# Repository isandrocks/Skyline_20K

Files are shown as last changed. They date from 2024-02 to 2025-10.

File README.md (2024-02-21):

# Skyline_20K
 This is a 20 key keypad with really REALLY bright lights!

 This board has 12 4960 Neopixel LED's. they are all facing down for a massive aount of under glow if I make a white 3D printed case for it, or I can just use it as a searchlight. 

The keypad PCB has 2 brakepoints so it can be snapped off and then connected with a right angle header.

this also acts as a sort of stand for the keypad if you dont make a case for it.

skyline_3d 

skyline_PCB

Test configuration for the snap away parts 

skyline_mu

### First prototype done but i messed up the pads for the lighting so i need to redo some parts 

skyline_proto
skyline_proto

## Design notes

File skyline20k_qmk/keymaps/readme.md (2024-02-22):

# skyline20k

skyline20k

*A short description of the keyboard/project*

* Keyboard Maintainer: [iSandRocks](https://github.com/iSandRocks)
* Hardware Supported: *The PCBs, controllers supported*
* Hardware Availability: *Links to where you can find this hardware*

Make example for this keyboard (after setting up your build environment):

    make skyline20k:default

Flashing example for this keyboard:

    make skyline20k:default:flash

See the [build environment setup](https://docs.qmk.fm/#/getting_started_build_tools) and the [make instructions](https://docs.qmk.fm/#/getting_started_make_guide) for more information. Brand new to QMK? Start with our [Complete Newbs Guide](https://docs.qmk.fm/#/newbs).

## Bootloader

Enter the bootloader in 3 ways:

* **Bootmagic reset**: Hold down the key at (0,0) in the matrix (usually the top left key or Escape) and plug in the keyboard
* **Physical reset button**: Briefly press the button on the back of the PCB - some may have pads you must short instead
* **Keycode in layout**: Press the key mapped to `QK_BOOT` if it is available

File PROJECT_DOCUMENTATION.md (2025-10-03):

# Skyline_20K Project Documentation

## Project Overview

### Purpose and Goals
Skyline_20K is a custom 20-key mechanical keypad/macropad featuring extremely bright RGB underglow lighting. This project combines hardware design, PCB engineering, 3D modeling, and firmware development to create a highly functional and visually striking input device for enthusiasts and power users.

### Problem It Solves
The project addresses several needs in the mechanical keyboard community:
- **Customizable Macro Input**: Provides 20 programmable keys for shortcuts, macros, and special functions
- **Visual Impact**: Features 12 high-intensity 4960 Neopixel LEDs for dramatic underglow effects
- **Modular Design**: Includes breakaway sections that can be snapped off and reconnected, offering flexible form factors
- **Open Source Hardware**: Fully open-source design allows community modifications and learning

### Why It Matters
This project demonstrates the intersection of hardware engineering, firmware development, and maker culture. It showcases:
- Complete end-to-end product development from PCB design to working firmware
- Integration of multiple technologies (USB, RGB lighting, QMK firmware)
- Practical application of microcontroller programming
- Community-driven hardware development practices

## Features & Functionality

### Key Features

#### Hardware Features
1. **20-Key Matrix Layout**: 5×4 grid layout optimized for numpad-style usage and macro programming
2. **Ultra-Bright RGB Lighting**: 
   - 12× 4960 Neopixel LEDs
   - All LEDs face downward for maximum underglow effect
   - Can serve as a functional searchlight due to light intensity
   - Optimized for white 3D-printed cases to maximize light diffusion
3. **Modular PCB Design**:
   - Two breakpoints allow sections to snap off
   - Right-angle header connections for reassembly
   - Detached sections can act as a stand for the keypad
4. **ATmega328P Microcontroller**: Reliable, well-documented 8-bit AVR processor
5. **USB Connectivity**: Direct USB interface using custom bootloader

#### Firmware Features
1. **QMK Firmware Support**: Industry-standard mechanical keyboard firmware
2. **Vial Configuration**: Real-time keymap editing without reflashing
3. **Multiple Layers**: Support for function layers and complex key mappings
4. **RGB Effects**: Pre-configured rainbow mood lighting effect with customizable parameters
5. **N-Key Rollover (NKRO)**: Full anti-ghosting support
6. **Bootmagic**: Configuration features accessible via key combinations

### Technical Highlights

#### Frameworks & Libraries
- **QMK Firmware**: Open-source keyboard firmware framework
- **WS2812 Driver**: Bitbang implementation for LED control with precise timing
- **USBaspLoader**: Custom USB bootloader for AVR microcontrollers
- **Vial**: Real-time keyboard configuration tool

#### Tools & Technologies
- **KiCad**: PCB design and schematic capture
  - Full PCB layout files (`.kicad_pcb`)
  - Schematic files (`.kicad_sch`)
  - Gerber files for manufacturing
- **3D Printing**: STL files for enclosure design (v4 and v7 variants)
- **AVRDUDE**: AVR programming tool for flashing firmware and bootloader
- **USB Protocol**: Custom USB device implementation

### Unique Aspects

1. **Breakaway Design**: Unlike typical keyboards, this features intentional breakpoints for modularity
2. **Extreme Lighting**: The 4960 Neopixel LEDs are significantly brighter than standard WS2812B LEDs
3. **Downward-Facing LEDs**: Unconventional LED orientation creates unique underglow effects
4. **Dual-Purpose Stand**: Broken-off sections serve as a functional stand
5. **Custom USB Bootloader**: Uses USBaspLoader instead of standard Arduino bootloader
6. **Complete Open Source**: Full hardware and firmware files available

## Architecture & Design

### High-Level Structure

The project consists of four main components:

```
Skyline_20K/
├── Hardware Design (KiCad files)
├── Firmware (QMK-based)
├── 3D Models (STL files)
└── Bootloader (USBaspLoader)
```

### Core Components

#### 1. Hardware Layer (PCB Design)
**Files**: `20Key_macropad.kicad_*`, Gerber files
- **Matrix Wiring**: 5 rows × 4 columns = 20 keys
  - Rows: B0, B1, B2, D6, D7
  - Columns: C0, C1, C2, C3
- **Diode Direction**: COL2ROW configuration prevents ghosting
- **LED Controller**: Pin C4 drives the WS2812 LED chain
- **USB Interface**: Native USB pins on ATmega328P
- **Power Management**: USB bus-powered design

**Mechanical Features**:
- Cherry MX compatible switch footprints
- Breakpoints with reinforced traces
- Right-angle header mounting holes
- Mounting holes for case attachment

#### 2. Firmware Layer (QMK)
**Location**: `skyline20k_qmk/`

**Key Files**:
- `config.h`: Hardware configuration and feature settings
- `rules.mk`: Build system configuration and feature flags
- `info.json`: Keyboard metadata and layout definition
- `keymaps/`: Multiple keymap configurations
  - `default/`: Basic functional layout
  - `vial/`: Real-time configurable layout with Vial support

**Configuration Highlights**:
```c
// LED Configuration
#define WS2812_DI_PIN C4      // LED data pin
#define RGBLED_NUM 12          // 12 LEDs total
#define RGBLIGHT_LIMIT_VAL 255 // Maximum brightness

// WS2812 Timing (bitbang driver)
WS2812_TIMING = 1200
WS2812_T1H = 640    // High pulse for '1'
WS2812_T0H = 320    // High pulse for '0'
WS2812_TRST_US = 75 // Reset time
```

#### 3. Bootloader Layer (USBaspLoader)
**Location**: `USBaspLoader/`

- **Purpose**: Allows firmware updates via USB without external programmer
- **Protocol**: Emulates USBasp programmer for compatibility with AVRDUDE
- **Features**:
  - Self-protection from accidental overwrites
  - Update capability for bootloader itself
  - Configurable entry conditions (button/jumper)

**Fuse Settings for ATmega328P**:
```
Low Fuse:  0xFF (16MHz external crystal)
High Fuse: 0xD8 (Bootloader enabled)
Ext Fuse:  0xFF (BOD disabled)
```

#### 4. 3D Model Layer
**Files**: `20Key_macropad v4.stl`, `20Key_macropad v7.stl`
- Designed for white filament to maximize light diffusion
- Multiple versions for iteration and improvements
- Mounting features for PCB attachment
- Provision for breakaway section stand

### Data Flow

1. **Key Press**: Physical switch closes → Matrix scan detects
2. **Processing**: QMK firmware processes → Keymap lookup → USB HID report
3. **USB Communication**: Report sent to host computer
4. **LED Control**: Parallel process drives WS2812 LEDs via bitbang protocol
5. **Configuration**: Vial allows real-time updates via USB without reflashing

### Design Patterns

1. **Matrix Scanning**: Efficient key detection with minimal I/O pins
2. **Interrupt-Driven USB**: Responsive USB communication
3. **State Machine**: LED effects implemented as state machines
4. **Layer System**: Multiple keymap layers for extended functionality
5. **Modular Configuration**: Separated hardware config from behavior logic

## Installation & Setup

### Prerequisites

#### Hardware Requirements
- Skyline_20K PCB (manufactured from Gerber files)
- 20× Cherry MX compatible switches
- 20× Keycaps
- 12× 4960 Neopixel RGB LEDs
- ATmega328P microcontroller (pre-soldered or socketed)
- USB cable (appropriate connector for your design)
- Optional: 3D printed case (STL files provided)

#### Software Requirements
- **QMK Build Environment**: 
  - QMK CLI tools
  - AVR-GCC toolchain
  - ARM GCC (for certain features)
- **AVRDUDE**: For flashing bootloader and firmware
- **Python 3.7+**: Required by QMK CLI
- **Git**: For cloning repositories
- **Optional**: Vial configurator for keymap customization

### Initial Hardware Setup

#### 1. Bootloader Installation
If starting with a blank ATmega328P, you'll need an ISP programmer:

```bash
# Set fuses (enables bootloader, sets clock to external 16MHz)
avrdude -c avrisp -p m328p -P /dev/ttyUSB0 -v -u -U lfuse:w:0xFF:m
avrdude -c avrisp -p m328p -P /dev/ttyUSB0 -v -u -U hfuse:w:0xD8:m
avrdude -c avrisp -p m328p -P /dev/ttyUSB0 -v -u -U efuse:w:0xFF:m

# Flash USBaspLoader
cd USBaspLoader
make DEVICE=atmega328p
make flash
```

**Note**: Replace `/dev/ttyUSB0` with your programmer's port (COM port on Windows).

#### 2. Assembly Steps
1. Solder LEDs to PCB (observe polarity!)
2. Solder switches into PCB
3. Install microcontroller (if socketed) or verify pre-soldered installation
4. Connect USB cable
5. Optional: Snap apart breakaway sections if desired
6. Optional: Install in 3D printed case

### Firmware Setup

#### Building QMK Firmware

1. **Install QMK Environment**:
```bash
# Install QMK CLI
python3 -m pip install --user qmk

# Setup QMK
qmk setup
```

2. **Clone Skyline_20K Repository**:
```bash
git clone https://github.com/isandrocks/Skyline_20K.git
cd Skyline_20K
```

3. **Link Keyboard to QMK**:
```bash
# Create symlink in QMK keyboards directory
ln -s $(pwd)/skyline20k_qmk ~/qmk_firmware/keyboards/skyline20k
```

4. **Build Firmware**:
```bash
# Build default keymap
qmk compile -kb skyline20k -km default

# Or build Vial keymap for real-time configuration
qmk compile -kb skyline20k -km vial
```

#### Flashing Firmware

**Using USBaspLoader** (after initial bootloader installation):
```bash
# Enter bootloader mode (press reset button or configured key combo)
qmk flash -kb skyline20k -km default

# AVRDUDE will automatically detect and flash
```

**Manual AVRDUDE command**:
```bash
avrdude -c usbasp -p m328p -U flash:w:skyline20k_default.hex
```

### Testing

1. **LED Test**: Upon power-up, LEDs should illuminate with default rainbow mood effect
2. **Key Test**: Use a key tester website or text editor to verify all 20 keys respond
3. **Layer Test**: Test function layer keys (if configured)
4. **USB Test**: Verify stable USB connection (no disconnects)

### Vial Configuration (Optional)

1. **Install Vial**:
   - Download from https://get.vial.today/
   - Flash `vial` keymap variant

2. **Configure**:
   - Launch Vial application
   - Connect Skyline_20K
   - Customize keymaps in real-time
   - Adjust RGB settings
   - Save configuration (stored in EEPROM)

## Usage

### Basic Operation

#### Default Keymap (Layer 0)
The default layout is configured as a standard numpad-style layout:
```
ESC   1     2     3
4     5     6     7
8     9     0     BSPC
TAB   Q     W     E
R     T     Y     U
```
(See `skyline20k_qmk/keymaps/default/keymap.c` for complete mapping)

#### Function Layer (Layer 1)
Access by holding the MO(1) key:
- Function keys (F1-F12)
- Arrow keys for navigation
- Volume controls
- Additional media keys

### Example Workflows

#### 1. **Number Pad Entry**
- Use as a dedicated number pad for data entry
- Efficient for spreadsheet work or calculator operations

#### 2. **Macro Programming**
```c
// Example custom macro in keymap.c
case MACRO_1:
    if (record->event.pressed) {
        SEND_STRING("git commit -m \"\"" SS_TAP(X_LEFT));
    }
    return false;
```

#### 3. **Media Control Center**
- Program keys for play/pause, next/previous track
- Volume controls
- Application launching

#### 4. **Gaming Hotkeys**
- Program frequently used game commands
- Quick access to inventory, skills, or macros
- Stream control for content creators

#### 5. **Creative Software Shortcuts**
- Photoshop/GIMP tool selection
- Video editing timeline controls
- 3D modeling shortcuts

### RGB Lighting Control

#### Default Effects
- **Rainbow Mood**: Slowly cycling rainbow effect (enabled by default)
- Brightness: Maximum (255)
- Hue start: 8
- Saturation: Maximum

#### Customizing RGB (via QMK)
Edit `skyline20k_qmk/config.h`:
```c
#define RGBLIGHT_HUE_STEP 8      // Hue change increment
#define RGBLIGHT_SAT_STEP 17     // Saturation change increment
#define RGBLIGHT_VAL_STEP 17     // Brightness change increment
#define RGBLIGHT_LIMIT_VAL 255   // Maximum brightness (reduce if too bright)
```

#### Available RGB Keycodes (add to keymap)
- `RGB_TOG`: Toggle RGB on/off
- `RGB_MOD`: Cycle through effects
- `RGB_HUI/RGB_HUD`: Increase/decrease hue
- `RGB_SAI/RGB_SAD`: Increase/decrease saturation
- `RGB_VAI/RGB_VAD`: Increase/decrease brightness

### Advanced Usage

#### Custom Firmware Modifications
1. Edit keymap in `skyline20k_qmk/keymaps/default/keymap.c`
2. Add custom RGB effects in keymap
3. Implement tap dance or leader key sequences
4. Add custom OLED display support (requires hardware mod)

#### Bootloader Entry
- **Hardware Method**: Short the bootloader entry pins during power-up
- **Software Method**: Configure a key combo to enter bootloader mode
- **Emergency**: Use ISP programmer to force reflash if bootloader corrupted

## Development Notes

### Current Status
- **Hardware**: Prototype completed with minor issues identified
- **PCB Issue**: First prototype had incorrect LED pad layout (documented in README)
- **Firmware**: Functional with QMK and Vial support
- **Case Design**: Multiple STL iterations available (v4, v7)

### Known Issues and Limitations

1. **LED Pad Misalignment** (Prototype v1):
   - Issue: LED pads not properly aligned for 4960 Neopixels
   - Status: Identified, requires PCB revision
   - Workaround: Manual wire connections for prototype testing

2. **Brightness Warning**:
   - 12× 4960 Neopixels at full brightness draw significant current
   - May exceed USB 2.0 500mA limit
   - Recommendation: Limit brightness or use powered USB hub

3. **Bootloader Entry**:
   - Requires physical button or jumper (hardware-dependent)
   - Software bootloader entry would improve user experience

4. **Documentation**:
   - Some documentation files incomplete (placeholders in QMK readme)
   - Assembly instructions could be more detailed

### Planned Improvements

#### Short Term
- [ ] Revise PCB to fix LED pad alignment
- [ ] Complete assembly documentation
- [ ] Add build photos to repository
- [ ] Create step-by-step soldering guide

#### Medium Term
- [ ] Design improved case with better LED diffusion
- [ ] Add rotary encoder support (hardware revision)
- [ ] Implement RGB per-key lighting mode
- [ ] Create configuration web interface
- [ ] Add OLED display support

#### Long Term
- [ ] Wireless variant (Bluetooth/2.4GHz)
- [ ] Hot-swap socket support for switches
- [ ] Split keyboard variant using breakaway design
- [ ] Metal case option for premium version
- [ ] Group buy or small production run

### Development Environment

#### Building from Source
```bash
# Clone repository
git clone https://github.com/isandrocks/Skyline_20K.git
cd Skyline_20K

# Build QMK firmware
cd skyline20k_qmk
qmk compile -kb skyline20k -km default

# Build bootloader (if modifying)
cd ../USBaspLoader
make clean
make DEVICE=atmega328p
```

#### Contributing
This is an open-source project welcoming contributions:
- PCB improvements
- Firmware enhancements
- Case design variations
- Documentation updates
- Bug fixes

### Testing Checklist
- [ ] All 20 keys register correctly
- [ ] No key ghosting in any combination
- [ ] All 12 LEDs illuminate
- [ ] RGB effects run smoothly
- [ ] USB connection stable
- [ ] No excessive heat generation
- [ ] Case fit (if using 3D printed enclosure)
- [ ] Breakaway mechanism works cleanly

## Potential Impact

### Who Benefits

1. **Mechanical Keyboard Enthusiasts**:
   - Custom hardware design inspiration
   - Learning resource for PCB design
   - Platform for experimentation

2. **Content Creators & Streamers**:
   - Quick access to streaming controls
   - Visual indicator for stream status (via RGB)
   - Customizable macro keys for OBS, Discord, etc.

3. **Software Developers**:
   - Programmable shortcuts for IDE functions
   - Git command macros
   - Build/test automation triggers

4. **Designers & Artists**:
   - Quick tool selection in creative software
   - Brush size/opacity controls
   - Timeline navigation shortcuts

5. **Data Entry Professionals**:
   - Dedicated numpad functionality
   - Ergonomic positioning options
   - Reduced hand travel

6. **Students & Educators**:
   - Learning platform for embedded systems
   - Example of complete product development cycle
   - Hands-on electronics and programming project

### Extension Possibilities

#### Hardware Variants
1. **Split Design**: Utilize breakaway feature to create true split numpad
2. **Ortholinear Layout**: Redesign with aligned columns for ergonomics
3. **Macro Pad Series**: 12-key, 16-key, 24-key variants
4. **Display Integration**: Add OLED for status and visual feedback
5. **Encoder Version**: Replace some keys with rotary encoders

#### Software Extensions
1. **Web Configurator**: Browser-based keymap editor
2. **Animation Library**: Pre-made RGB lighting effects
3. **Profile Manager**: Multiple keymap profiles for different applications
4. **Mobile App**: Bluetooth configuration app (for wireless variant)
5. **Integration Plugins**: Direct integration with popular software

#### Alternative Applications
1. **MIDI Controller**: Repurpose as music production tool
2. **Home Automation Interface**: Control smart home devices
3. **Presentation Remote**: Slide control with visual feedback
4. **Accessibility Device**: Custom input device for users with disabilities
5. **Industrial Control**: Simplified control panel for machinery

#### Community Projects
1. **Group Buy Organization**: Community-funded production run
2. **Case Design Contest**: Multiple community-designed enclosures
3. **Firmware Forks**: Specialized firmware variants
4. **Tutorial Series**: Video guides for assembly and programming
5. **Regional Meetups**: Hands-on build workshops

### Educational Value

This project serves as an excellent learning resource for:
- PCB design principles and KiCad workflow
- Embedded C programming
- USB protocol implementation
- AVR microcontroller architecture
- LED driver protocols (WS2812)
- Build system configuration (Makefiles)
- Git version control and collaboration
- Open-source hardware licensing
- Product development lifecycle

### Impact on Maker Community

1. **Knowledge Sharing**: Complete open-source design enables learning and remixing
2. **Lower Barriers**: Makes custom keyboard creation more accessible
3. **Innovation Platform**: Foundation for new ideas and variations
4. **Skill Development**: Real-world project for electronics and firmware skills
5. **Community Building**: Brings together hardware and software enthusiasts

## Additional Resources

### Official Links
- **Main Repository**: https://github.com/isandrocks/Skyline_20K
- **Maintainer**: iSandRocks (https://github.com/iSandRocks)
- **License**: GPL-2.0-or-later (firmware), check individual components for specific licenses

### Documentation & Guides
- **QMK Documentation**: https://docs.qmk.fm/
- **QMK Getting Started**: https://docs.qmk.fm/#/newbs
- **Vial Project**: https://get.vial.today/
- **USBaspLoader Project**: http://matrixstorm.com/avr/tinyusbboard/
- **KiCad Documentation**: https://docs.kicad.org/

### Technical References
- **ATmega328P Datasheet**: https://ww1.microchip.com/downloads/en/DeviceDoc/Atmel-7810-Automotive-Microcontrollers-ATmega328P_Datasheet.pdf
- **WS2812 LED Datasheet**: https://cdn-shop.adafruit.com/datasheets/WS2812.pdf
- **USB HID Specification**: https://www.usb.org/hid
- **AVR-GCC Compiler**: https://gcc.gnu.org/wiki/avr-gcc

### Tools & Software
- **QMK Firmware**: https://github.com/qmk/qmk_firmware
- **Vial**: https://github.com/vial-kb/vial-gui
- **KiCad EDA**: https://www.kicad.org/
- **AVRDUDE**: https://www.nongnu.org/avrdude/
- **PrusaSlicer / Cura**: For 3D printing cases

### Community Resources
- **QMK Discord**: https://discord.gg/qmk
- **r/MechanicalKeyboards**: https://reddit.com/r/MechanicalKeyboards
- **r/olkb**: https://reddit.com/r/olkb (ortholinear/custom keyboards)
- **Deskthority Wiki**: https://deskthority.net/wiki/
- **GeekHack Forums**: https://geekhack.org/

### Learning Resources
- **QMK Tutorial Series**: https://docs.qmk.fm/#/newbs
- **PCB Design Tutorial**: https://www.youtube.com/watch?v=35YuILUlfGs (Contextual Electrons)
- **AVR Programming**: "Make: AVR Programming" by Elliot Williams
- **USB Protocol**: "USB Complete" by Jan Axelson

### Similar Projects for Reference
- **BDN9 Macropad**: 3×3 macropad with RGB underglow
- **MayPad**: Open-source numpad design
- **Sweet16**: 4×4 macropad by 1upkeyboards
- **Discipline**: Through-hole keyboard demonstrating similar techniques

### Manufacturing Resources
- **PCB Fabrication**:
  - JLCPCB: https://jlcpcb.com/
  - PCBWay: https://www.pcbway.com/
  - OSH Park: https://oshpark.com/
- **Components**:
  - Mouser Electronics: https://www.mouser.com/
  - DigiKey: https://www.digikey.com/
  - AliExpress: (for switches, LEDs, keycaps)
- **3D Printing Services**:
  - Shapeways: https://www.shapeways.com/
  - Sculpteo: https://www.sculpteo.com/
  - Local makerspaces and libraries

### File Formats in Repository
- `.kicad_pcb` - PCB layout (open with KiCad)
- `.kicad_sch` - Schematic (open with KiCad)
- `.kicad_pro` - KiCad project file
- `.stl` - 3D model for printing (open with slicer software)
- `.c/.h` - C source and header files (firmware)
- `.json` - Configuration files for QMK/Vial
- `.mk` - Makefile for build system

### Support & Contact
For questions, issues, or contributions:
1. Open an issue on GitHub repository
2. Check existing issues for similar problems
3. Provide detailed information (PCB version, firmware version, steps to reproduce)
4. Include photos for hardware issues

---

**Document Version**: 1.0  
**Last Updated**: 2024  
**Prepared for**: AI Blog Post Generation Agent  
**Project Status**: Active Development, Prototype Stage

This documentation is intended to provide comprehensive context for creating a detailed, informative blog post about the Skyline_20K project. It covers all technical aspects, use cases, and community impact of this open-source hardware project.

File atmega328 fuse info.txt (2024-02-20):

#ATMega328P Fuses
avrdude -c avrisp -p m328p -P (replace with port) -v -u -U lfuse:w:0xFF:m
avrdude -c avrisp -p m328p -P (replace with port) -v -u -U hfuse:w:0xD8:m
avrdude -c avrisp -p m328p -P (replace with port) -v -u -U efuse:w:0xFF:m

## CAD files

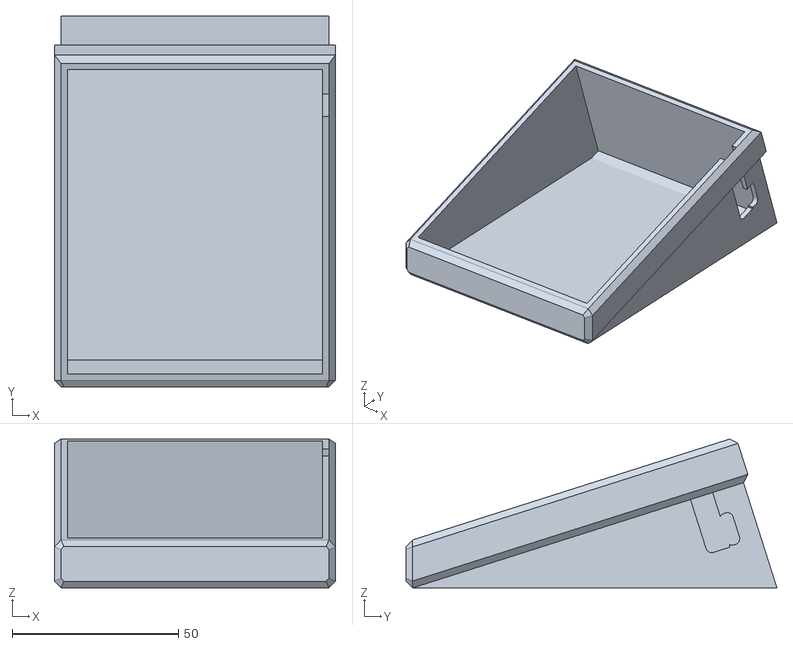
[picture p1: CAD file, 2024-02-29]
20Key_macropad v7.stl
84.7 x 111.7 x 44.8

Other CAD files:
20Key_macropad v4.stl

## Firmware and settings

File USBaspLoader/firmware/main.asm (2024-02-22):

main.elf:     file format elf32-avr

SYMBOL TABLE:
00800100 l    d  .data	00000000 .data
00007000 l    d  .text	00000000 .text
00800106 l    d  .bss	00000000 .bss
0080013b l    d  .noinit	00000000 .noinit
00000000 l    d  .comment	00000000 .comment
00000000 l    d  .note.gnu.avr.deviceinfo	00000000 .note.gnu.avr.deviceinfo
00000000 l    d  .debug_aranges	00000000 .debug_aranges
00000000 l    d  .debug_info	00000000 .debug_info
00000000 l    d  .debug_abbrev	00000000 .debug_abbrev
00000000 l    d  .debug_line	00000000 .debug_line
00000000 l    d  .debug_frame	00000000 .debug_frame
00000000 l    d  .debug_str	00000000 .debug_str
00000000 l    d  .debug_line_str	00000000 .debug_line_str
00000000 l    d  .debug_loclists	00000000 .debug_loclists
00000000 l    d  .debug_macro	00000000 .debug_macro
00000000 l    d  .debug_rnglists	00000000 .debug_rnglists
00000000 l    df *ABS*	00000000 main.c
0000003e l       *ABS*	00000000 __SP_H__
0000003d l       *ABS*	00000000 __SP_L__
0000003f l       *ABS*	00000000 __SREG__
00000000 l       *ABS*	00000000 __tmp_reg__
00000001 l       *ABS*	00000000 __zero_reg__
000070e4 l       .text	00000000 .Loc.0
000070e4 l       .text	00000000 L0
000070e4 l       .text	00000000 .Loc.1
000070f4 l       .text	00000000 __BOOTLOADERENTRY_FROMSOFTWARE__bootup_investigate_RAMEND_done6
000070f2 l       .text	00000000 __BOOTLOADERENTRY_FROMSOFTWARE__bootup_investigate_RAMEND_mismatch6
0080013c l     O .noinit	00000001 __BOOTLOADERENTRY_FROMSOFTWARE__bootup_RAMEND_doesmatch
0080013b l     O .noinit	00000001 __BOOTLOADERENTRY_FROMSOFTWARE__bootup_MCUCSR
000070fc l       .text	00000000 .Loc.2
000070fc l       .text	00000000 L0
00007382 l       .text	00000000 .Loc.3
00007382 l       .text	00000000 L0
00007382 l       .text	00000000 .Loc.4
00007384 l       .text	00000000 .Loc.5
00007384 l       .text	00000000 .Loc.6
00007384 l       .text	00000000 .Loc.7
00007384 l       .text	00000000 .Loc.8
00007386 l       .text	00000000 .Loc.9
00007386 l       .text	00000000 .Loc.10
00007388 l       .text	00000000 .Loc.11
0000738c l       .text	00000000 .Loc.12
00007392 l       .text	00000000 .Loc.13
00007392 l       .text	00000000 .Loc.14
00007394 l       .text	00000000 .Loc.15
00007398 l       .text	00000000 .Loc.16
00007398 l       .text	00000000 .Loc.17
00007398 l       .text	00000000 .Loc.18
0000739a l       .text	00000000 .Loc.19
0000739c l       .text	00000000 .Loc.20
0000739e l       .text	00000000 .Loc.21
00800102 l     O .data	00000004 signatureBytes
000073a4 l       .text	00000000 .Loc.22
000073a6 l       .text	00000000 .Loc.23
000073a6 l       .text	00000000 .Loc.24
000073aa l       .text	00000000 .Loc.25
000073ae l       .text	00000000 .Loc.26
000073ae l       .text	00000000 .Loc.27
000073ae l       .text	00000000 .Loc.28
000073b2 l       .text	00000000 .Loc.29
000073b2 l       .text	00000000 .Loc.30
000073b2 l       .text	00000000 .Loc.31
000073b8 l       .text	00000000 .Loc.32
000073ba l       .text	00000000 .Loc.33
000073ba l       .text	00000000 .Loc.34
000073ba l       .text	00000000 .Loc.35
000073ba l       .text	00000000 .Loc.36
000073c0 l       .text	00000000 .Loc.37
000073c0 l       .text	00000000 .Loc.38
000073c6 l       .text	00000000 .Loc.39
000073c6 l       .text	00000000 .Loc.40
000073c6 l       .text	00000000 .Loc.41
000073c8 l       .text	00000000 .Loc.42
000073c8 l       .text	00000000 .Loc.43
000073cc l       .text	00000000 .Loc.44
000073d0 l       .text	00000000 .Loc.45
000073d0 l       .text	00000000 .Loc.46
000073d0 l       .text	00000000 .Loc.47
000073d6 l       .text	00000000 .Loc.48
000073d8 l       .text	00000000 .Loc.49
000073d8 l       .text	00000000 .Loc.50
000073d8 l       .text	00000000 .Loc.51
000073de l       .text	00000000 .Loc.52
000073de l       .text	00000000 .Loc.53
000073e2 l       .text	00000000 .Loc.54
000073e6 l       .text	00000000 .Loc.55
000073e6 l       .text	00000000 .Loc.56
000073ea l       .text	00000000 .Loc.57
000073ea l       .text	00000000 .Loc.58
000073ea l       .text	00000000 .Loc.59
000073ea l       .text	00000000 .Loc.60
000073ee l       .text	00000000 .Loc.61
000073f0 l       .text	00000000 .Loc.62
000073f0 l       .text	00000000 .Loc.63
000073f2 l       .text	00000000 .Loc.64
000073f2 l       .text	00000000 .Loc.65
000073f2 l       .text	00000000 .Loc.66
000073f2 l       .text	00000000 .Loc.67
000073f2 l       .text	00000000 .Loc.68
000073f4 l       .text	00000000 .Loc.69
000073f4 l       .text	00000000 .Loc.70
000073f8 l       .text	00000000 .Loc.71
000073f8 l       .text	00000000 .Loc.72
000073f8 l       .text	00000000 .Loc.73
000073f8 l       .text	00000000 .Loc.74
000073fc l       .text	00000000 .Loc.75
000073fe l       .text	00000000 .Loc.76
00007400 l       .text	00000000 .Loc.77
00007402 l       .text	00000000 .Loc.78
00007402 l       .text	00000000 .Loc.79
00007402 l       .text	00000000 .Loc.80
00007406 l       .text	00000000 .Loc.81
00007406 l       .text	00000000 .Loc.82
00007408 l       .text	00000000 .Loc.83
00007408 l       .text	00000000 .Loc.84
0000740c l       .text	00000000 .Loc.85
00007410 l       .text	00000000 .Loc.86
00007412 l       .text	00000000 .Loc.87
00007412 l       .text	00000000 .Loc.88
00007416 l       .text	00000000 .Loc.89
00007416 l       .text	00000000 .Loc.90
00800139 l     O .bss	00000001 stayinloader
0000741e l       .text	00000000 L0
0000741e l       .text	00000000 .Loc.91
0000741e l       .text	00000000 L0
0000741e l       .text	00000000 .Loc.92
0000741e l       .text	00000000 .Loc.93
0000741e l       .text	00000000 .Loc.94
0000741e l       .text	00000000 .Loc.95
00007420 l       .text	00000000 .Loc.96
00007420 l       .text	00000000 .Loc.97
00007424 l       .text	00000000 .Loc.98
00007424 l       .text	00000000 .Loc.99
00007424 l       .text	00000000 .Loc.100
00007424 l       .text	00000000 .Loc.101
00007428 l       .text	00000000 .Loc.102
00007428 l       .text	00000000 .Loc.103
0000742c l       .text	00000000 .Loc.104
0000742c l       .text	00000000 .Loc.105
0000742c l       .text	00000000 .Loc.106
00007430 l       .text	00000000 _mywait_sleeploop263
00007438 l       .text	00000000 .Loc.107
00007438 l       .text	00000000 .Loc.108
00007438 l       .text	00000000 .Loc.109
00007438 l       .text	00000000 .Loc.110
00007438 l       .text	00000000 .Loc.111
0000743e l       .text	00000000 .Loc.112
00007442 l       .text	00000000 .Loc.113
00007442 l       .text	00000000 .Loc.114
00007446 l       .text	00000000 .Loc.115
0000744a l       .text	00000000 .Loc.116
0000744a l       .text	00000000 .Loc.117
0000744e l       .text	00000000 .Loc.118
0000744e l       .text	00000000 .Loc.119
0000744e l       .text	00000000 .Loc.120
0000744e l       .text	00000000 .Loc.121
00007450 l       .text	00000000 .Loc.122
00007452 l       .text	00000000 .Loc.123
00007452 l       .text	00000000 .Loc.124
00007452 l       .text	00000000 .Loc.125
00007452 l       .text	00000000 .Loc.126
00007454 l       .text	00000000 .Loc.127
00007454 l       .text	00000000 .Loc.128
00007456 l       .text	00000000 .Loc.129
00007456 l       .text	00000000 .Loc.130
0000745a l       .text	00000000 .Loc.131
0000745a l       .text	00000000 .Loc.132
0000745e l       .text	00000000 .Loc.133
0000745e l       .text	00000000 .Loc.134
00007460 l       .text	00000000 .Loc.135
00007466 l       .text	00000000 .Loc.136
00007466 l       .text	00000000 .Loc.137
0000746c l       .text	00000000 .Loc.138
0000746c l       .text	00000000 .Loc.139
0000746e l       .text	00000000 .Loc.140
0000746e l       .text	00000000 .Loc.141
0000746e l       .text	00000000 .Loc.142
0000746e l       .text	00000000 .Loc.143
0000746e l       .text	00000000 .Loc.144
00007484 l       .text	00000000 .Loc.145
00007484 l       .text	00000000 .Loc.146
00007484 l       .text	00000000 .Loc.147
00007484 l       .text	00000000 .Loc.148
00007484 l       .text	00000000 .Loc.149
00007488 l       .text	00000000 .Loc.150
0000748e l       .text	00000000 .Loc.151
0000748e l       .text	00000000 .Loc.152
00007490 l       .text	00000000 .Loc.153
00007490 l       .text	00000000 .Loc.154
00007492 l       .text	00000000 .Loc.155
00007492 l       .text	00000000 .Loc.156
00007492 l       .text	00000000 .Loc.157
00007498 l       .text	00000000 _mywait_sleeploop376
000074a0 l       .text	00000000 .Loc.158
000074a0 l       .text	00000000 .Loc.159
000074a2 l       .text	00000000 .Loc.160
000074a4 l       .text	00000000 .Loc.161
000074a4 l       .text	00000000 .Loc.162
000074a4 l       .text	00000000 .Loc.163
000074a4 l       .text	00000000 .Loc.164
000074a4 l       .text	00000000 .Loc.165
000074a4 l       .text	00000000 .Loc.166
000074a4 l       .text	00000000 .Loc.167
000074aa l       .text	00000000 .Loc.168
000074aa l       .text	00000000 .Loc.169
000074ae l       .text	00000000 .Loc.170
000074ae l       .text	00000000 .Loc.171
000074ba l       .text	00000000 .Loc.172
000074be l       .text	00000000 .Loc.173
000074be l       .text	00000000 .Loc.174
000074be l       .text	00000000 .Loc.175
000074be l       .text	00000000 .Loc.176
000074be l       .text	00000000 .Loc.177
000074c6 l       .text	00000000 L0
000074c8 l       .text	00000000 .Loc.178
000074c8 l       .text	00000000 .Loc.179
000074cc l       .text	00000000 L0
000074ce l       .text	00000000 .Loc.180
000074ce l       .text	00000000 .Loc.181
000074ce l       .text	00000000 .Loc.182
000074d4 l       .text	00000000 .Loc.183
000074d4 l       .text	00000000 .Loc.184
000074da l       .text	00000000 .Loc.185
000074da l       .text	00000000 .Loc.186
0080013a l     O .bss	00000001 usbMsgFlags
000074de l       .text	00000000 .Loc.187
000074de l       .text	00000000 .Loc.188
000074e0 l       .text	00000000 .Loc.189
000074e4 l       .text	00000000 .Loc.190
000074e4 l       .text	00000000 .Loc.191
000074e6 l       .text	00000000 .Loc.192
000074ea l       .text	00000000 L0
000074ec l       .text	00000000 .Loc.193
000074ec l       .text	00000000 .Loc.194
000074ec l       .text	00000000 .Loc.195
000074ec l       .text	00000000 .Loc.196
000074ec l       .text	00000000 .Loc.197
000074ec l       .text	00000000 .Loc.198
000074ec l       .text	00000000 .Loc.199
00800130 l     O .bss	00000004 replyBuffer.0
000074f8 l       .text	00000000 .Loc.200
000074f8 l       .text	00000000 .Loc.201
000074fc l       .text	00000000 .Loc.202
000074fc l       .text	00000000 .Loc.203
000074fe l       .text	00000000 .Loc.204
00007500 l       .text	00000000 .Loc.205
00007504 l       .text	00000000 .Loc.206
00007504 l       .text	00000000 .Loc.207
00007504 l       .text	00000000 .Loc.208
00007504 l       .text	00000000 .Loc.209
00007506 l       .text	00000000 .Loc.210
00007506 l       .text	00000000 .Loc.211
00007506 l       .text	00000000 .Loc.212
00007506 l       .text	00000000 .Loc.213
00007516 l       .text	00000000 .Loc.214
00007516 l       .text	00000000 .Loc.215
0000751a l       .text	00000000 L0
0000751c l       .text	00000000 .Loc.216
00007520 l       .text	00000000 L0
00007522 l       .text	00000000 .Loc.217
00007522 l       .text	00000000 .Loc.218
00007524 l       .text	00000000 .Loc.219
00007526 l       .text	00000000 .Loc.220
0000752a l       .text	00000000 L0
0000752c l       .text	00000000 .Loc.221
0000752c l       .text	00000000 .Loc.222
00800137 l     O .bss	00000002 currentAddress
00007538 l       .text	00000000 .Loc.223
00007538 l       .text	00000000 .Loc.224
0000753c l       .text	00000000 .Loc.225
0000753c l       .text	00000000 .Loc.226
0000753e l       .text	00000000 .Loc.227
00800136 l     O .bss	00000001 bytesRemaining
00007542 l       .text	00000000 .Loc.228
00007542 l       .text	00000000 .Loc.229
00007546 l       .text	00000000 .Loc.230
00800135 l     O .bss	00000001 isLastPage
0000754a l       .text	00000000 .Loc.231
0000754a l       .text	00000000 .Loc.232
00800134 l     O .bss	00000001 currentRequest
0000754e l       .text	00000000 .Loc.233
0000754e l       .text	00000000 .Loc.234
0000754e l       .text	00000000 .Loc.235
0000754e l       .text	00000000 .Loc.236
0000754e l       .text	00000000 .Loc.237
00007552 l       .text	00000000 .Loc.238
00007552 l       .text	00000000 .Loc.239
00007558 l       .text	00000000 .Loc.240
00007558 l       .text	00000000 .Loc.241
00800100 l     O .data	00000001 usbMsgLen
0000755c l       .text	00000000 .Loc.242
0000755c l       .text	00000000 .Loc.243
0000755c l       .text	00000000 .Loc.244
00007560 l       .text	00000000 .Loc.245
00007560 l       .text	00000000 .Loc.246
00007564 l       .text	00000000 .Loc.247
00007568 l       .text	00000000 .Loc.248
00007568 l       .text	00000000 .Loc.249
0000756c l       .text	00000000 .Loc.250
00007570 l       .text	00000000 L0
00007572 l       .text	00000000 .Loc.251
00007572 l       .text	00000000 .Loc.252
00007572 l       .text	00000000 .Loc.253
00007572 l       .text	00000000 .Loc.254
00007572 l       .text	00000000 .Loc.255
00007572 l       .text	00000000 .Loc.256
00007572 l       .text	00000000 .Loc.257
0000757a l       .text	00000000 .Loc.258
0000757a l       .text	00000000 .Loc.259
00007582 l       .text	00000000 .Loc.260
00007582 l       .text	00000000 .Loc.261
0000758e l       .text	00000000 .Loc.262
0000758e l       .text	00000000 .Loc.263
0000758e l       .text	00000000 .Loc.264
0000758e l       .text	00000000 .Loc.265
00007592 l       .text	00000000 .Loc.266
00007592 l       .text	00000000 .Loc.267
00007592 l       .text	00000000 .Loc.268
00007592 l       .text	00000000 .Loc.269
0000759a l       .text	00000000 .Loc.270
0000759a l       .text	00000000 .Loc.271
0000759a l       .text	00000000 .Loc.272
0000759c l       .text	00000000 .Loc.273
0000759c l       .text	00000000 .Loc.274
000075a4 l       .text	00000000 .Loc.275
000075a4 l       .text	00000000 .Loc.276
000075a4 l       .text	00000000 .Loc.277
000075a8 l       .text	00000000 .Loc.278
000075ac l       .text	00000000 .Loc.279
000075ac l       .text	00000000 .Loc.280
000075ae l       .text	00000000 .Loc.281
000075b2 l       .text	00000000 .Loc.282
000075b2 l       .text	00000000 .Loc.283
000075b2 l       .text	00000000 .Loc.284
000075b6 l       .text	00000000 .Loc.285
000075b6 l       .text	00000000 .Loc.286
000075ba l       .text	00000000 .Loc.287
000075ba l       .text	00000000 .Loc.288
000075ba l       .text	00000000 .Loc.289
000075ba l       .text	00000000 .Loc.290
000075ba l       .text	00000000 .Loc.291
000075ba l       .text	00000000 .Loc.292
000075ba l       .text	00000000 .Loc.293
000075bc l       .text	00000000 .Loc.294
000075bc l       .text	00000000 .Loc.295
000075c0 l       .text	00000000 .Loc.296
000075c0 l       .text	00000000 .Loc.297
000075c0 l       .text	00000000 .Loc.298
000075c4 l       .text	00000000 .Loc.299
000075c4 l       .text	00000000 .Loc.300
000075c4 l       .text	00000000 .Loc.301
000075c4 l       .text	00000000 .Loc.302
000075c8 l       .text	00000000 .Loc.303
000075c8 l       .text	00000000 .Loc.304
000075c8 l       .text	00000000 .Loc.305
000075cc l       .text	00000000 .Loc.306
000075ce l       .text	00000000 .Loc.307
000075ce l       .text	00000000 .Loc.308
000075ce l       .text	00000000 .Loc.309
000075ce l       .text	00000000 .Loc.310
000075d6 l       .text	00000000 .Loc.311
000075d6 l       .text	00000000 .Loc.312
000075d8 l       .text	00000000 .Loc.313
000075dc l       .text	00000000 .Loc.314
000075dc l       .text	00000000 .Loc.315
000075e0 l       .text	00000000 .Loc.316
000075e0 l       .text	00000000 .Loc.317
000075e0 l       .text	00000000 .Loc.318
000075e4 l       .text	00000000 .Loc.319
000075e6 l       .text	00000000 .Loc.320
000075ea l       .text	00000000 .Loc.321
000075ec l       .text	00000000 .Loc.322
000075ec l       .text	00000000 .Loc.323
000075ec l       .text	00000000 .Loc.324
000075ec l       .text	00000000 .Loc.325
000075ec l       .text	00000000 .Loc.326
000075ec l       .text	00000000 .Loc.327
000075f0 l       .text	00000000 .Loc.328
000075f0 l       .text	00000000 .Loc.329
000075f0 l       .text	00000000 .Loc.330
000075f0 l       .text	00000000 .Loc.331
000075f0 l       .text	00000000 .Loc.332
000075f4 l       .text	00000000 .Loc.333
000075fc l       .text	00000000 .Loc.334
000075fe l       .text	00000000 .Loc.335
000075fe l       .text	00000000 .Loc.336
000075fe l       .text	00000000 .Loc.337
00007600 l       .text	00000000 .Loc.338
00007604 l       .text	00000000 .Loc.339
00007604 l       .text	00000000 .Loc.340
00007604 l       .text	00000000 .Loc.341
00007604 l       .text	00000000 .Loc.342
00007604 l       .text	00000000 .Loc.343
00007606 l       .text	00000000 .Loc.344
0000760a l       .text	00000000 .Loc.345
0000760a l       .text	00000000 .Loc.346
0000760a l       .text	00000000 .Loc.347
0000760a l       .text	00000000 .Loc.348
0000760a l       .text	00000000 .Loc.349
0000760e l       .text	00000000 .Loc.350
00007610 l       .text	00000000 .Loc.351
00007614 l       .text	00000000 .Loc.352
00007614 l       .text	00000000 .Loc.353
00007614 l       .text	00000000 .Loc.354
00007618 l       .text	00000000 .Loc.355
00007618 l       .text	00000000 .Loc.356
00007618 l       .text	00000000 .Loc.357
00007618 l       .text	00000000 .Loc.358
00007618 l       .text	00000000 .Loc.359
0000761c l       .text	00000000 .Loc.360
00007628 l       .text	00000000 .Loc.361
0000762c l       .text	00000000 .Loc.362
0000762c l       .text	00000000 .Loc.363
0000762c l       .text	00000000 .Loc.364
0000762c l       .text	00000000 .Loc.365
0000762c l       .text	00000000 .Loc.366
00007630 l       .text	00000000 .Loc.367
0000763c l       .text	00000000 .Loc.368
00007640 l       .text	00000000 .Loc.369
00007640 l       .text	00000000 .Loc.370
00007640 l       .text	00000000 .Loc.371
00007640 l       .text	00000000 .Loc.372
00007640 l       .text	00000000 .Loc.373
00007644 l       .text	00000000 .Loc.374
00007650 l       .text	00000000 .Loc.375
00007650 l       .text	00000000 .Loc.376
00007654 l       .text	00000000 .Loc.377
00007658 l       .text	00000000 .Loc.378
00007658 l       .text	00000000 .Loc.379
0000765c l       .text	00000000 .Loc.380
0000765c l       .text	00000000 .Loc.381
0000765c l       .text	00000000 .Loc.382
0000765e l       .text	00000000 .Loc.383
0000765e l       .text	00000000 .Loc.384
00007660 l       .text	00000000 .Loc.385
00007664 l       .text	00000000 L0
0000766a l       .text	00000000 .Loc.386
0000766e l       .text	00000000 .Loc.387
00007670 l       .text	00000000 .Loc.388
00007672 l       .text	00000000 .Loc.389
00007672 l       .text	00000000 .Loc.390
00007674 l       .text	00000000 .Loc.391
00007676 l       .text	00000000 .Loc.392
00007676 l       .text	00000000 .Loc.393
00007676 l       .text	00000000 .Loc.394
0000767e l       .text	00000000 .Loc.395
0000767e l       .text	00000000 .Loc.396
0000767e l       .text	00000000 .Loc.397
0000767e l       .text	00000000 .Loc.398
0000767e l       .text	00000000 .Loc.399
0000767e l       .text	00000000 .Loc.400
00007688 l       .text	00000000 .Loc.401
00007688 l       .text	00000000 .Loc.402
0000768e l       .text	00000000 .Loc.403
0000768e l       .text	00000000 .Loc.404
0000768e l       .text	00000000 .Loc.405
00007690 l       .text	00000000 .Loc.406
00007690 l       .text	00000000 .Loc.407
00007694 l       .text	00000000 .Loc.408
00007694 l       .text	00000000 .Loc.409
00007694 l       .text	00000000 .Loc.410
00007694 l       .text	00000000 .Loc.411
00007698 l       .text	00000000 .Loc.412
00007698 l       .text	00000000 .Loc.413
0000769e l       .text	00000000 .Loc.414
0000769e l       .text	00000000 .Loc.415
000076a6 l       .text	00000000 .Loc.416
000076ae l       .text	00000000 .Loc.417
000076ae l       .text	00000000 .Loc.418
000076b0 l       .text	00000000 .Loc.419
000076be l       .text	00000000 .Loc.420
000076c0 l       .text	00000000 .Loc.421
000076c0 l       .text	00000000 .Loc.422
000076c2 l       .text	00000000 .Loc.423
000076c4 l       .text	00000000 .Loc.424
000076c4 l       .text	00000000 .Loc.425
000076ca l       .text	00000000 .Loc.426
000076ca l       .text	00000000 .Loc.427
000076ce l       .text	00000000 .Loc.428
000076ce l       .text	00000000 .Loc.429
000076d0 l       .text	00000000 .Loc.430
000076e8 l       .text	00000000 .Loc.431
000076ea l       .text	00000000 .Loc.432
000076ea l       .text	00000000 .Loc.433
000076fc l       .text	00000000 .Loc.434
000076fc l       .text	00000000 .Loc.435
000076fc l       .text	00000000 .Loc.436
00007700 l       .text	00000000 .Loc.437
00007704 l       .text	00000000 .Loc.438
00007708 l       .text	00000000 .Loc.439
0000770c l       .text	00000000 .Loc.440
0000770e l       .text	00000000 .Loc.441
00007710 l       .text	00000000 .Loc.442
00007718 l       .text	00000000 .Loc.443
00007718 l       .text	00000000 .Loc.444
0000771a l       .text	00000000 .Loc.445
0000772c l       .text	00000000 .Loc.446
0000772e l       .text	00000000 .Loc.447
0000772e l       .text	00000000 .Loc.448
0000772e l       .text	00000000 .Loc.449
00007734 l       .text	00000000 .Loc.450
00007734 l       .text	00000000 .Loc.451
00007736 l       .text	00000000 .Loc.452
00007748 l       .text	00000000 .Loc.453
0000774a l       .text	00000000 .Loc.454
0000774a l       .text	00000000 .Loc.455
0000774a l       .text	00000000 .Loc.456
00007750 l       .text	00000000 .Loc.457
00007752 l       .text	00000000 .Loc.458
0000775a l       .text	00000000 .Loc.459
0000775e l       .text	00000000 .Loc.460
0000775e l       .text	00000000 .Loc.461
0000775e l       .text	00000000 .Loc.462
00007762 l       .text	00000000 .Loc.463
00007766 l       .text	00000000 .Loc.464
00007766 l       .text	00000000 .Loc.465
00007766 l       .text	00000000 .Loc.466
00007766 l       .text	00000000 .Loc.467
00007766 l       .text	00000000 .Loc.468
00007770 l       .text	00000000 .Loc.469
00007770 l       .text	00000000 .Loc.470
00007776 l       .text	00000000 .Loc.471
00007776 l       .text	00000000 .Loc.472
0000777a l       .text	00000000 .Loc.473
0000777c l       .text	00000000 .Loc.474
00007784 l       .text	00000000 .Loc.475
00007788 l       .text	00000000 .Loc.476
00007788 l       .text	00000000 .Loc.477
00007790 l       .text	00000000 .Loc.478
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

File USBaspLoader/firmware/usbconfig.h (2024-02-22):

/* Name: usbconfig.h
 * Project: V-USB, virtual USB port for Atmel's(r) AVR(r) microcontrollers
 * Author: Christian Starkjohann
 * Creation Date: 2005-04-01
 * Tabsize: 4
 * Copyright: (c) 2005 by OBJECTIVE DEVELOPMENT Software GmbH
 * License: GNU GPL v2 (see License.txt), GNU GPL v3 or proprietary (CommercialLicense.txt)
 */

#ifndef __usbconfig_h_included__
#define __usbconfig_h_included__

/* YOU SHOULD NOT NEED TO MODIFY THIS FILE! All configurations are supposed
 * to go into bootloaderconfig.h!
 */

/* ---------------------------- Hardware Config ---------------------------- */

/* All the port and pin assignments, as well as the clock speed and CRC
   setting are now in bootloaderconfig.h: */

#include "bootloaderconfig.h"

/* --------------------------- Functional Range ---------------------------- */

#define USB_CFG_HAVE_INTRIN_ENDPOINT    0
/* Define this to 1 if you want to compile a version with two endpoints: The
 * default control endpoint 0 and an interrupt-in endpoint (any other endpoint
 * number).
 */
#define USB_CFG_HAVE_INTRIN_ENDPOINT3   0
/* Define this to 1 if you want to compile a version with three endpoints: The
 * default control endpoint 0, an interrupt-in endpoint 3 (or the number
 * configured below) and a catch-all default interrupt-in endpoint as above.
 * You must also define USB_CFG_HAVE_INTRIN_ENDPOINT to 1 for this feature.
 */
#define USB_CFG_EP3_NUMBER              3
/* If the so-called endpoint 3 is used, it can now be configured to any other
 * endpoint number (except 0) with this macro. Default if undefined is 3.
 */
/* #define USB_INITIAL_DATATOKEN           USBPID_DATA1 */
/* The above macro defines the startup condition for data toggling on the
 * interrupt/bulk endpoints 1 and 3. Defaults to USBPID_DATA1.
 * Since the token is toggled BEFORE sending any data, the first packet is
 * sent with the oposite value of this configuration!
 */
#define USB_CFG_IMPLEMENT_HALT          0
/* Define this to 1 if you also want to implement the ENDPOINT_HALT feature
 * for endpoint 1 (interrupt endpoint). Although you may not need this feature,
 * it is required by the standard. We have made it a config option because it
 * bloats the code considerably.
 */
#define USB_CFG_SUPPRESS_INTR_CODE      0
/* Define this to 1 if you want to declare interrupt-in endpoints, but don't
 * want to send any data over them. If this macro is defined to 1, functions
 * usbSetInterrupt() and usbSetInterrupt3() are omitted. This is useful if
 * you need the interrupt-in endpoints in order to comply to an interface
 * (e.g. HID), but never want to send any data. This option saves a couple
 * of bytes in flash memory and the transmit buffers in RAM.
 */
#define USB_CFG_INTR_POLL_INTERVAL      10
/* If you compile a version with endpoint 1 (interrupt-in), this is the poll
 * interval. The value is in milliseconds and must not be less than 10 ms for
 * low speed devices.
 */
#ifndef USB_CFG_IS_SELF_POWERED // allow bootloaderconfig.h to override
#define USB_CFG_IS_SELF_POWERED         0
#endif
/* Define this to 1 if the device has its own power supply. Set it to 0 if the
 * device is powered from the USB bus.
 */
#ifndef USB_CFG_MAX_BUS_POWER   // allow bootloaderconfig.h to override
#define USB_CFG_MAX_BUS_POWER           100
#endif
/* Set this variable to the maximum USB bus power consumption of your device.
 * The value is in milliamperes. [It will be divided by two since USB
 * communicates power requirements in units of 2 mA.]
 */
#define USB_CFG_IMPLEMENT_FN_WRITE      1
/* Set this to 1 if you want usbFunctionWrite() to be called for control-out
 * transfers. Set it to 0 if you don't need it and want to save a couple of
 * bytes.
 */
#define USB_CFG_IMPLEMENT_FN_READ       1
/* Set this to 1 if you need to send control replies which are generated
 * "on the fly" when usbFunctionRead() is called. If you only want to send
 * data from a static buffer, set it to 0 and return the data from
 * usbFunctionSetup(). This saves a couple of bytes.
 */
#define USB_CFG_IMPLEMENT_FN_WRITEOUT   0
/* Define this to 1 if you want to use interrupt-out (or bulk out) endpoints.
 * You must implement the function usbFunctionWriteOut() which receives all
 * interrupt/bulk data sent to any endpoint other than 0. The endpoint number
 * can be found in 'usbRxToken'.
 */
#define USB_CFG_HAVE_FLOWCONTROL        0
/* Define this to 1 if you want flowcontrol over USB data. See the definition
 * of the macros usbDisableAllRequests() and usbEnableAllRequests() in
 * usbdrv.h.
 */
#if defined(BOOTLOADER_ADDRESS)
#	define USB_CFG_DRIVER_FLASH_PAGE       (BOOTLOADER_ADDRESS >> 16)
#else
#	define USB_CFG_DRIVER_FLASH_PAGE       0
#endif
/* If the device has more than 64 kBytes of flash, define this to the 64 k page
 * where the driver's constants (descriptors) are located. Or in other words:
 * Define this to 1 for boot loaders on the ATMega128.
 */
#define USB_CFG_LONG_TRANSFERS          0
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

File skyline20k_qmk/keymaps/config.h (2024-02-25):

// Copyright 2024 iSandRocks (@iSandRocks)
// SPDX-License-Identifier: GPL-2.0-or-later

#pragma once
// The pin connected to the data pin of the LEDs
#define WS2812_DI_PIN C4
// The number of LEDs connected
#define RGBLED_NUM 12

#define RGBLIGHT_HUE_STEP 8
#define RGBLIGHT_SAT_STEP 17
#define RGBLIGHT_VAL_STEP 17
#define RGBLIGHT_LIMIT_VAL 255

#define RGBLIGHT_EFFECT_RAINBOW_MOOD

#define RGBLIGHT_DEFAULT_HUE 8
#define RGBLIGHT_DEFAULT_SAT UINT8_MAX
#define RGBLIGHT_DEFAULT_VAL RGBLIGHT_LIMIT_VAL
#define RGBLIGHT_DEFAULT_SPD 0
#define RGBLIGHT_DEFAULT_ON true




/*
 * Feature disable options
 *  These options are also useful to firmware size reduction.
 */

/* disable debug print */
/*#define NO_DEBUG*/

/* disable print */
//#define NO_PRINT

/* disable action features */
//#define NO_ACTION_LAYER
//#define NO_ACTION_TAPPING
//#define NO_ACTION_ONESHOT

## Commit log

2024-02-20 Create atmega328 fuse info.txt
2024-02-22 fix issue with LEDs
    LED's were facing the wrong way due to an issue withe the footprint. also removed the capacitors as they were not needed with only 12 lights
    [20Key_macropad-B_Cu.gbr, 20Key_macropad-B_Mask.gbr, 20Key_macropad-B_Paste.gbr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]
2024-02-24 Bird update
    [20Key_macropad v4.stl]
2024-02-29 new case added
    [20Key_macropad v7.stl]
